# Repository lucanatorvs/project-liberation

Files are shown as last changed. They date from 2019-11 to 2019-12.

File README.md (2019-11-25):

# Project Liberation
Project Liberation is een weerstation welke doormiddel van een ESP-32 over WiFi
de meet-data naar het Britse meteorologisch instituut
([MetOffice](https://www.metoffice.gov.uk/)) communiceert zodat deze beschikbaar
worden in de [WOW-NL](https://wow.knmi.nl/) database van de KNMI.

## assembling
for assembling instructions pleas see the pdf at ./instructions/instructions.pdf

## flashing the esp
Use a 'USB to serial' programer and conect the pins: 3v3, GND, RXD, TXD, DTR and RTS. 
Remember that the RX on the programer sould go to the TX on the esp and so the pcb, and visversa.
In arduino, open the scetch and select the port of youre programer.
Install the esp32 boardmaniger by adding the url `https://dl.espressif.com/dl/package_esp32_index.json` to the "additional board maniger URLs" section in youre arduino settings.
A list of the drivers is given and if all the drivers are installed, you sould be able to flach the esp.

## Keeping our logs clean
Please read this and keep it in mind when writing commit messages:
[How to Write a Git Commit Message](https://chris.beams.io/posts/git-commit/)

Also, please put this in your `~/.gitconfig` (if you care why read 
[this](https://kalamuna.atlassian.net/wiki/display/KALA/Git+Workflow)):
```
[branch]
  autosetuprebase = always
[core]
  mergeoptions = --no-commit --no-ff
```

## Contibuting
Pull requests are welcome. For major changes, please open an issue first to discuss what you would like to change.

## Licence
[MIT](./LICENSE)

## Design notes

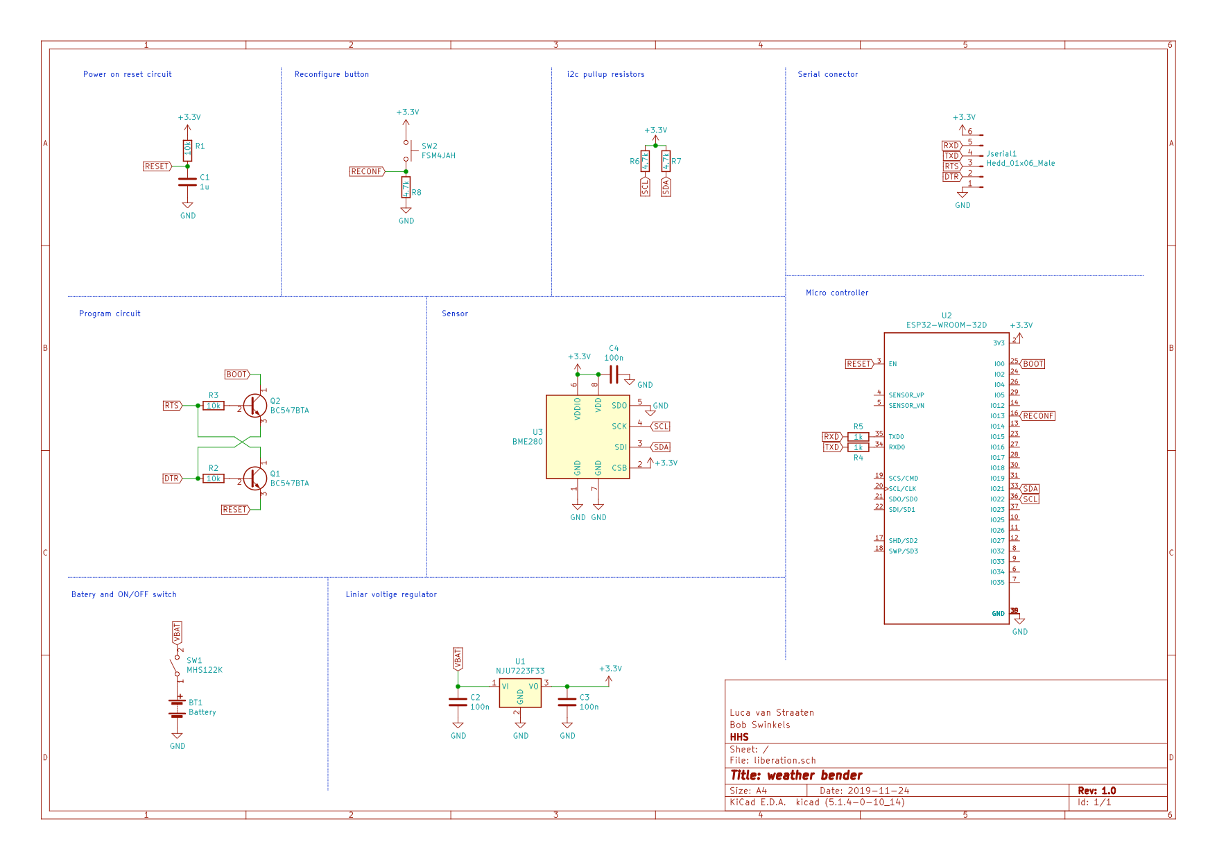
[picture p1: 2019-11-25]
instructions/schematic.png

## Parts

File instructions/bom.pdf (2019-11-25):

### bill of material

Id | Designator | Package | Quantity | Designation
1 | R3,R1,R2 | Weerstand | 3 | 10k
2 | C1 | Condensator | 1 | 1u
3 | C2,C3,C4 | Condensator | 3 | 100n
4 | Jserial1 | PinHeader_1x06_P2.54mm_Vertical | 1 | Hedd_01x06_Male
5 | Q2,Q1 | Transistor_npn | 2 | BC547BTA
6 | R5,R4 | Weerstand | 2 | 1k
7 | R6,R7,R8 | Weerstand | 3 | 4.7k
8 | SW1 | Schakelaar | 1 | MHS122K
9 | SW2 | Knop | 1 | FSM4JAH
10 | BT1 | Batterij houder | 1 | Battery
11 | U1 | Voltage regulator | 1 | NJU7223F33

1

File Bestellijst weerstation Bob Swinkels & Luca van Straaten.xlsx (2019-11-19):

# | Bedrijfsnaam | Naam van het product | Directe link naar product | Bestelnr. / Order code | Aantal | Prijs/st ; incl BTW | Totaal | Opmerking door/voor besteller
1 | Mouser | ESP32-WROOM-32D | https://nl.mouser.com/ProductDetail/Espressif-Systems/ESP32-WROOM-32D | 356-ESP32WROOM-32D | 27 | €4.14 | €111.73 | MCU
2 | Mouser | BME280 | https://nl.mouser.com/ProductDetail/Bosch-Sensortec/BME280 | 262-BME280 | 27 | €4.07 | €109.77 | Sensor
3 | Mouser | MHS122K | https://nl.mouser.com/ProductDetail/Apem/MHS122K?qs=sGAEpiMZZMtHXLepoqNyVZHUmh3BZZ%2FL5BB0Uv5Iez0%3D | 642-MHS122K | 27 | €1.51 | €40.84 | Power switch
4 | Mouser | FSM4JAH | https://nl.mouser.com/ProductDetail/TE-Connectivity-Alcoswitch/FSM4JAH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 | 506-FSM4JAH | 27 | €0.11 | €2.87 | Push button
5 | Mouser | Keystone 2477 | https://nl.mouser.com/ProductDetail/Keystone-Electronics/2477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 | 534-2477 | 27 | €1.63 | €44.10 | Battery holder
6 | Mouser | NJU7223F33 | https://nl.mouser.com/ProductDetail/NJR/NJU7223F33 | 513-NJU7223F33 | 27 | €1.12 | €30.19 | 3.3V Regulator
7 | Mouser | BC547BTA | https://nl.mouser.com/ProductDetail/ON-Semiconductor-Fairchild/BC547BTA | 512-BC547BTA | 100 | €0.06 | €6.41 | NPN-Transistor
8 | Mouser | MFR3-10KFC | https://nl.mouser.com/ProductDetail/Welwyn-Components-TT-Electronics/MFR3-10KFC | 756-MFR3-10KFC | 100 | €0.04 | €3.51 | 10k Resistor
9 | Mouser | MFR3-4K7FC | https://nl.mouser.com/ProductDetail/Welwyn-Components-TT-Electronics/MFR3-4K7FC | 756-MFR3-4K7FC | 100 | €0.04 | €3.51 | 4k7 Resistor
10 | Mouser | MFR3-1K0FC | https://nl.mouser.com/ProductDetail/Welwyn-Components-TT-Electronics/MFR3-1K0FC | 756-MFR3-1K0FC | 100 | €0.04 | €3.51 | 1k0 Resistor
11 | Mouser | K104K15X7RF53H5 | https://nl.mouser.com/ProductDetail/Vishay-BC-Components/K104K15X7RF53H5 | 594-K104K15X7RF53H5 | 125 | €0.05 | €6.05 | 100n Capacitor
12 | Mouser | 860020672005 | https://nl.mouser.com/ProductDetail/Wurth-Elektronik/860020672005 | 710-860020672005 | 40 | €0.09 | €3.63 | 1u Capacitor
13 | Mouser | LR6XWA/B2 | https://nl.mouser.com/ProductDetail/Panasonic-Battery/LR6XWA-B2 | 658-LR6XWA/2SB | 100 | €0.40 | €39.93 | Battery
 |  |  |  |  |  | Totaal: | €406.06 | inclusief BTW
 |  |  |  |  |  | Totaal: | €16.24 | Per unit (+ ca. €2,- voor de PCB)

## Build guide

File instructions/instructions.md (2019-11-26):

---
author:
- Bob Swinkels
- Luca van Straaten 
header-includes:
	- \usepackage{pdfpages}
...

# WOW Monitor
### A project by Bob Swinkels and Luca van Straaten
 
--- 

## start:
do you have all the components?

check your components against the bill of materials. 

|Id |Designator|Package |Quantity|Designation |
|---|---|---|---|---|
|1  |R3,R1,R2  |Weerstand |3 |10k |
|2  |C1 |Condensator |1 |1u |
|3  |C2,C3,C4  |Condensator |3 |100n |
|4  |Jserial1  |PinHeader_1x06_P2.54mm_Vertical|1 |Hedd_01x06_Male|
|5  |Q2,Q1 |Transistor_npn |2 |BC547BTA |
|6  |R5,R4 |Weerstand |2 |1k |
|7  |R6,R7,R8  |Weerstand |3 |4.7k |
|8  |SW1 |Schakelaar |1 |MHS122K |
|9  |SW2 |Knop |1 |FSM4JAH |

## soldering!

Now it is time to start SOLDERING!!!
Start withe the small components and finish with the battery holder, remember to put some double sided tape on the battery holder befor you solder it for strength.

So start with the resistors (the small cilinders with 2 wires), the value is written on the piece of paper. you can also decode the colorcode, look at the decoder that is attached or just google "resistor color code".

Now continu with the progressively larger components. after you are done sodering, "flash" your bord with the Arduino IDE. Bob or luca can help you with that, but you can do it yourself! (witch is arguably more fun) Just follow the instructions on the GitHub projectpage. https://github.com/lucanatorvs/project-liberation

\pagebreak

## setting up your wether station to connect with the WOW server:
when you get home, start by setting up your account with the metoffice. go to http://wow.metoffice.gov.uk/sites and klick "Sign Up", "new account", fill in your info and register!
now check your email for login instructions. click the link in your mail and log back in. now go to "http://wow.metoffice.gov.uk" and click on "enter a site".

now fill in the location, and the site name, the time zone, and as the "Authentication Key" think of an 6 digit number. NOT "123456". and remember this!!!
At "Above Ground Measurements" for "Air Temperature" select "Hecto Pascal". 
At "Pressure" for "Pressure At Station" select "Hecto Pascal"
At "Other Observations" for "Relative Humidity" select "Captured"
leave the rest alone.
now fill in other relative information is aplicable.
after you filed in all your info click accept.

Now if you get the "Site Created!" message, your almost done! click "view sites" and in the colom "Search for Users Sites:" check out your new site. under the map is a code like "8b9cd787-930f-ea11-b265-0003ff5990ac", this is your site id, remember to copy it without the brackets but with the " - ".
now turn on your WOW monitor sensor bord, and hold the button. hold it until a new wifi network is avalible, "WOW-MONITOR-****" klick it and you should be redirected to a website in wich you have to fill in the "site id" and the 6 digit number. then connect to your wifi network.

http://wow.metoffice.gov.uk/sites

https://github.com/lucanatorvs/project-liberation

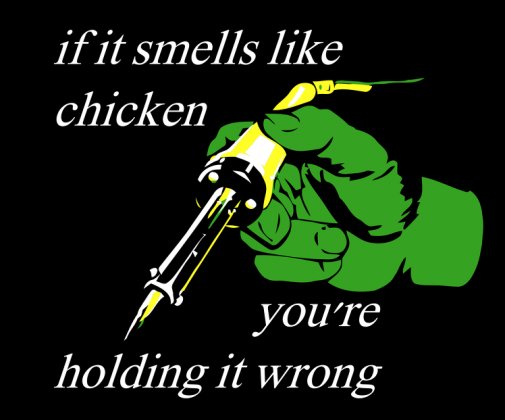
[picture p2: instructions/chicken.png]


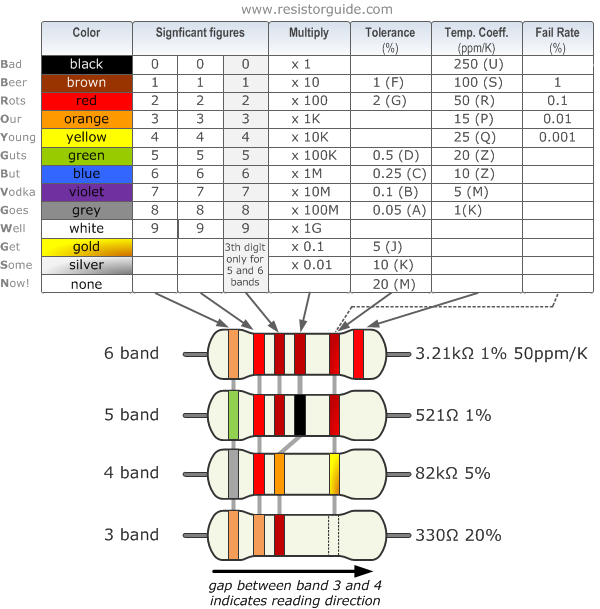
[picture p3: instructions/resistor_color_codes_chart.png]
van: https://www.resistorguide.com/standards-and-codes/resistor-color-code/resistor_color_codes_chart/


\includepdf[page={1}]{schematic.pdf}

\includepdf[page={1}]{pcb.pdf}

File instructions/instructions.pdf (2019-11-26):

## WOW Monitor

A project by Bob Swinkels and Luca van Straaten

start:

do you have all the components?

check your components against the bill of materials.

Id | Designator | Package | Quantity | Designation
1 | R3,R1,R2 | Weerstand | 3 | 10k
2 | C1 | Condensator | 1 | 1u
3 | C2,C3,C4 | Condensator | 3 | 100n
4 | Jserial1 | PinHeader_1x06_P2.54mm_Vertical | 1 | Hedd_01x06_Male
5 | Q2,Q1 | Transistor_npn | 2 | BC547BTA
6 | R5,R4 | Weerstand | 2 | 1k
7 | R6,R7,R8 | Weerstand | 3 | 4.7k
8 | SW1 | Schakelaar | 1 | MHS122K
9 | SW2 | Knop | 1 | FSM4JAH

soldering!

Now it is time to start SOLDERING!!! Start withe the small components and finish with the battery holder, remember to put some double sided tape on the battery holder befor you solder it for strength.

So start with the resistors (the small cilinders with 2 wires), the value is written on the piece of paper. you can also decode the colorcode, look at the decoder that is attached or just google “resistor color code”.

Now continu with the progressively larger components. after you are done sodering, “flash” your bord with the Arduino IDE. Bob or luca can help you with that, but you can do it yourself! (witch is arguably more fun) Just follow the instructions on the GitHub projectpage. https://github.com/lucanatorvs/project-liberation

1

setting up your wether station to connect with the WOW server:

when you get home, start by setting up your account with the metoffice. go to http://wow.metoffice.gov.uk/sites and klick “Sign Up”, “new account”, fill in your info and register! now check your email for login instructions. click the link in your mail and log back in. now go to “http://wow.metoffice.gov.uk” and click on “enter a site”.

now fill in the location, and the site name, the time zone, and as the “Authentication Key” think of an 6 digit number. NOT “123456”. and remember this!!! At “Above Ground Measurements” for “Air Temperature” select “Hecto Pascal”. At “Pressure” for “Pressure At Station” select “Hecto Pascal” At “Other Observations” for “Relative Humidity” select “Captured” leave the rest alone. now fill in other relative information is aplicable. after you filed in all your info click accept.

Now if you get the “Site Created!” message, your almost done! click “view sites” and in the colom “Search for Users Sites:” check out your new site. under the map is a code like “8b9cd787-930f-ea11-b265-0003ff5990ac”, this is your site id, remember to copy it without the brackets but with the " - “. now turn on your WOW monitor sensor bord, and hold the button. hold it until a new wifi network is avalible,”WOW-MONITOR-****" klick it and you should be redirected to a website in wich you have to fill in the “site id” and the 6 digit number. then connect to your wifi network.

Figure 1: http://wow.metoffice.gov.uk/sites

2

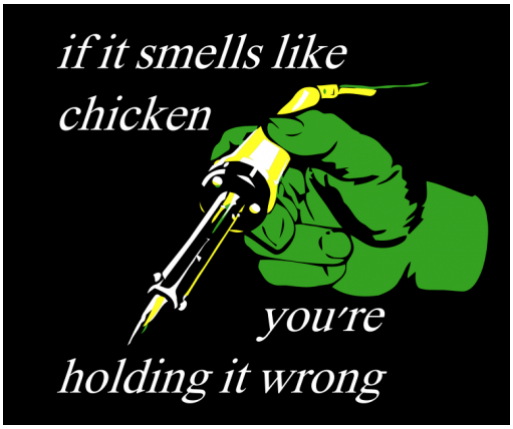
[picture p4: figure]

3

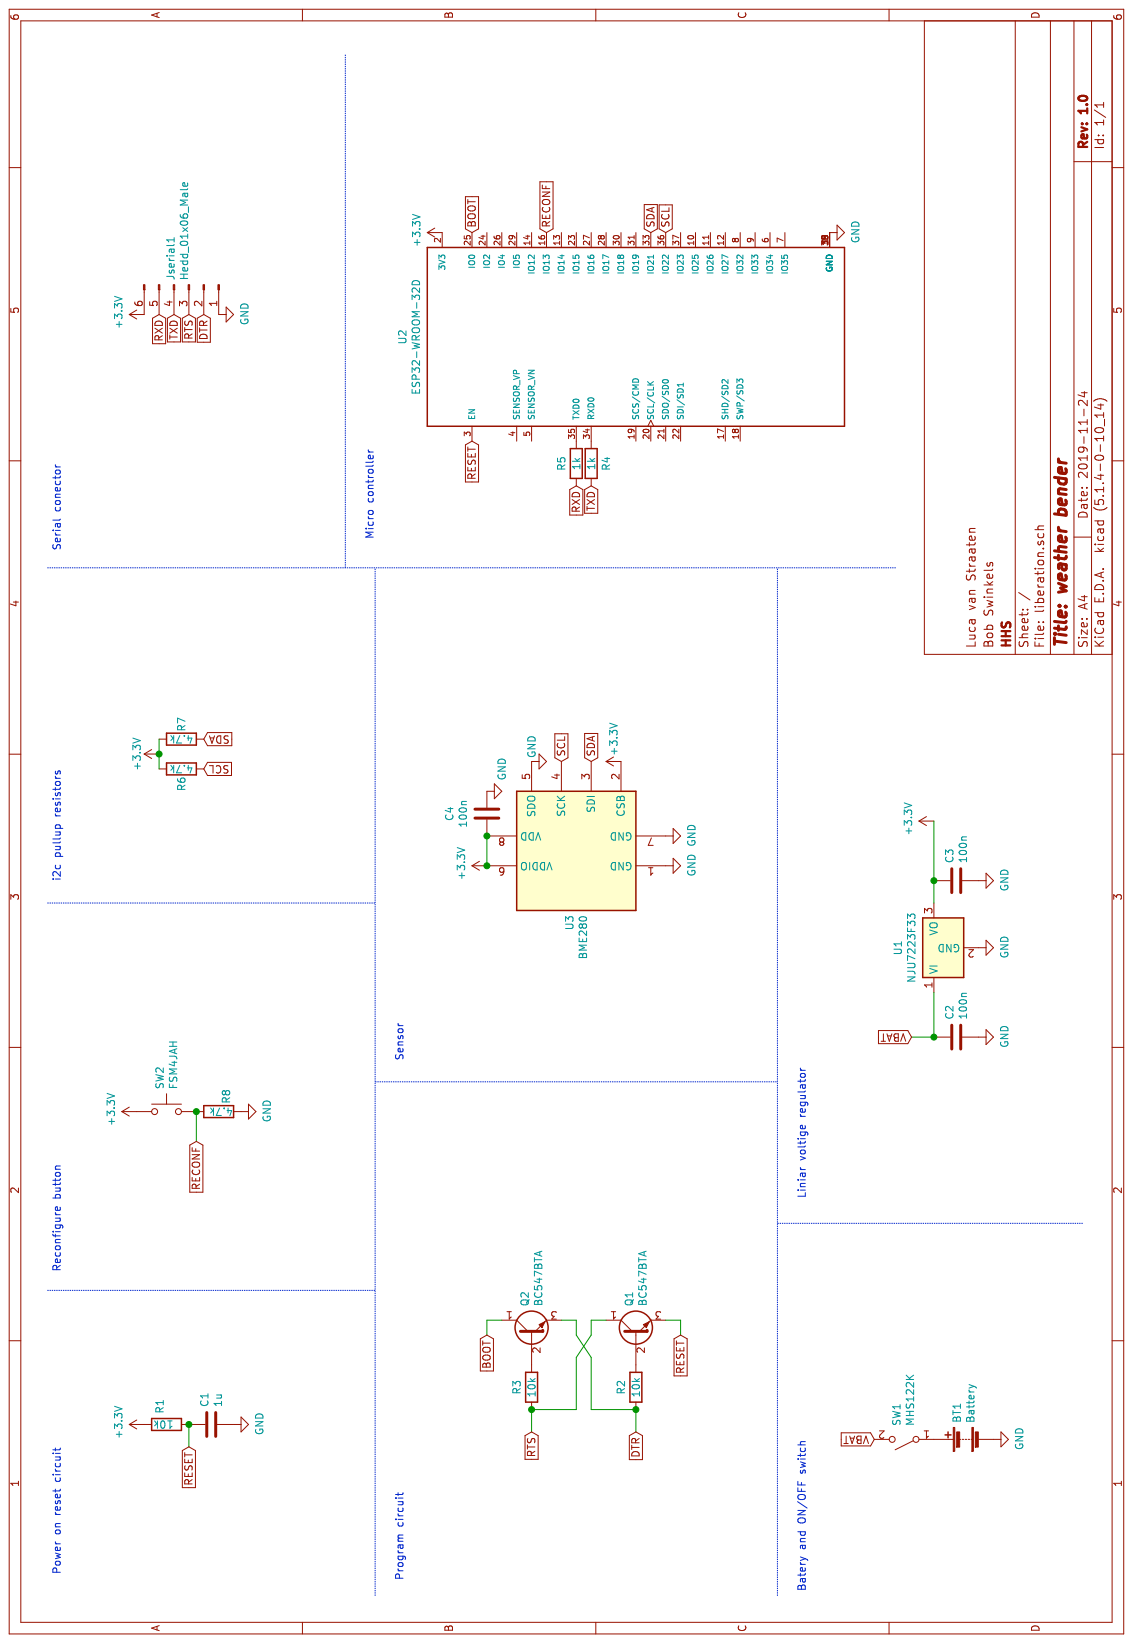
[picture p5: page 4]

Figure 2: https://github.com/lucanatorvs/project-liberation


Figure 3: van: https://www.resistorguide.com/standards-and-codes/resistorcolor-code/resistor_color_codes_chart/

5

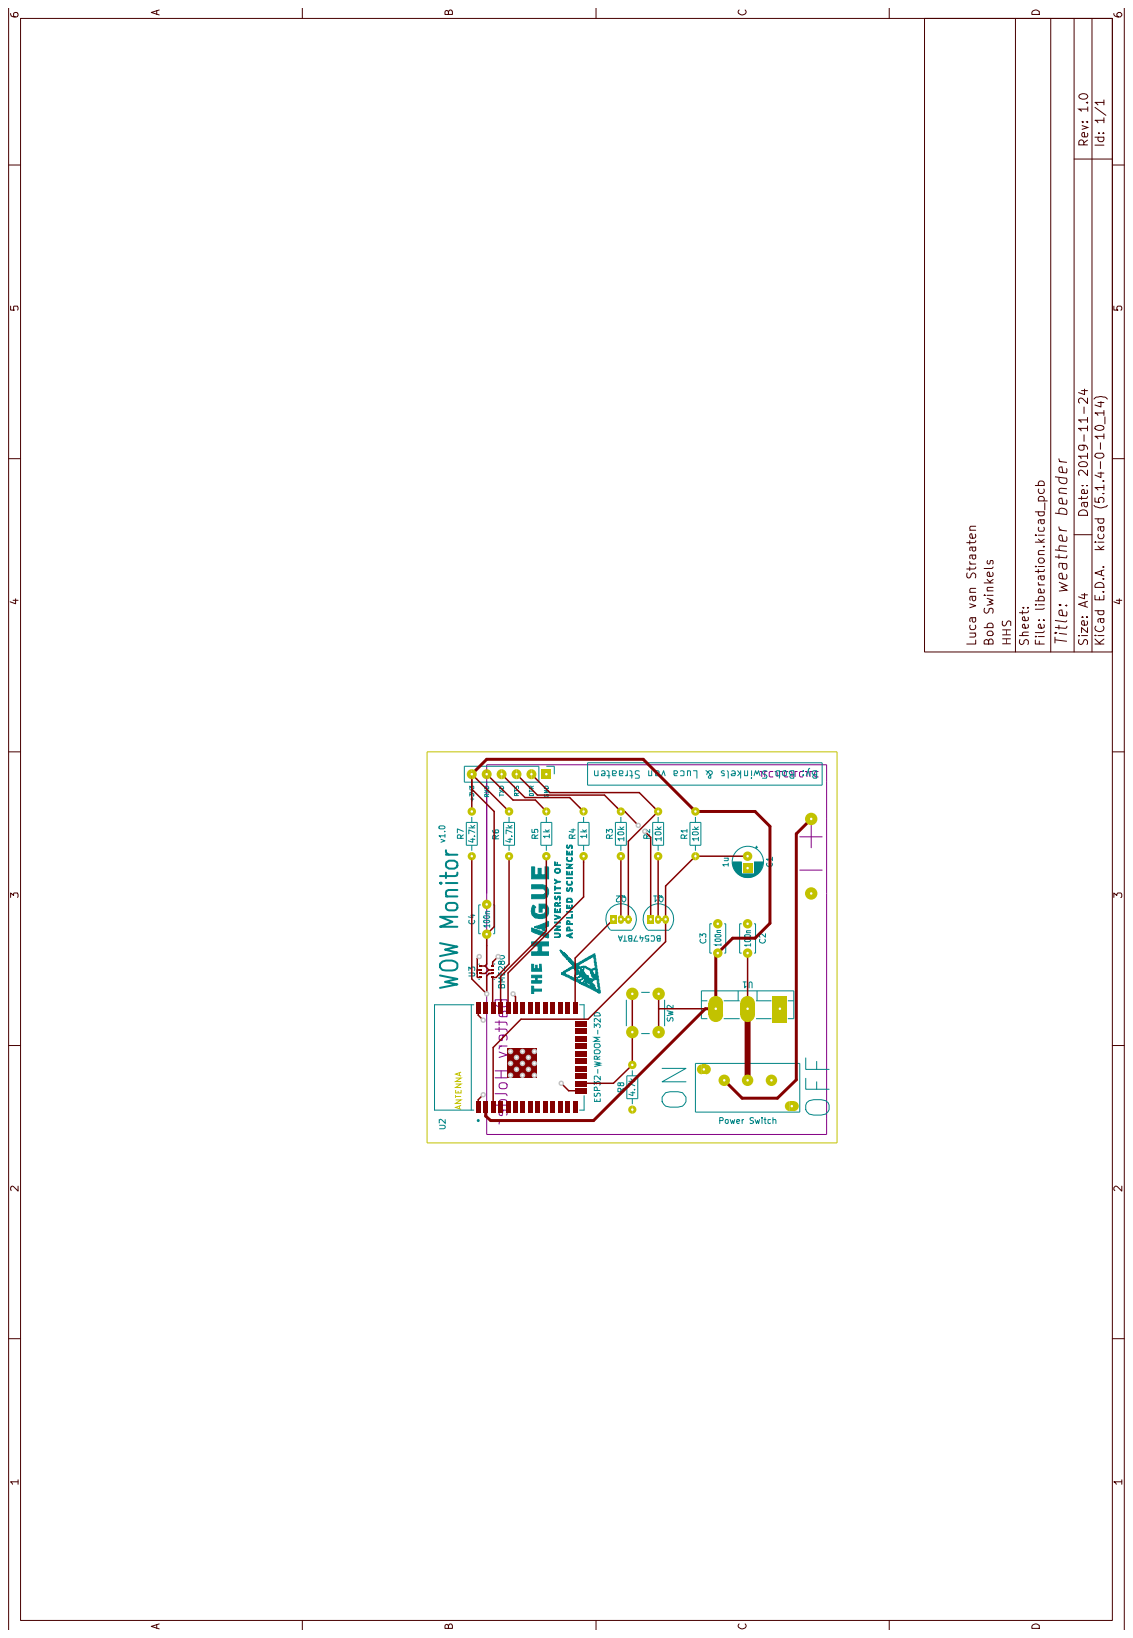
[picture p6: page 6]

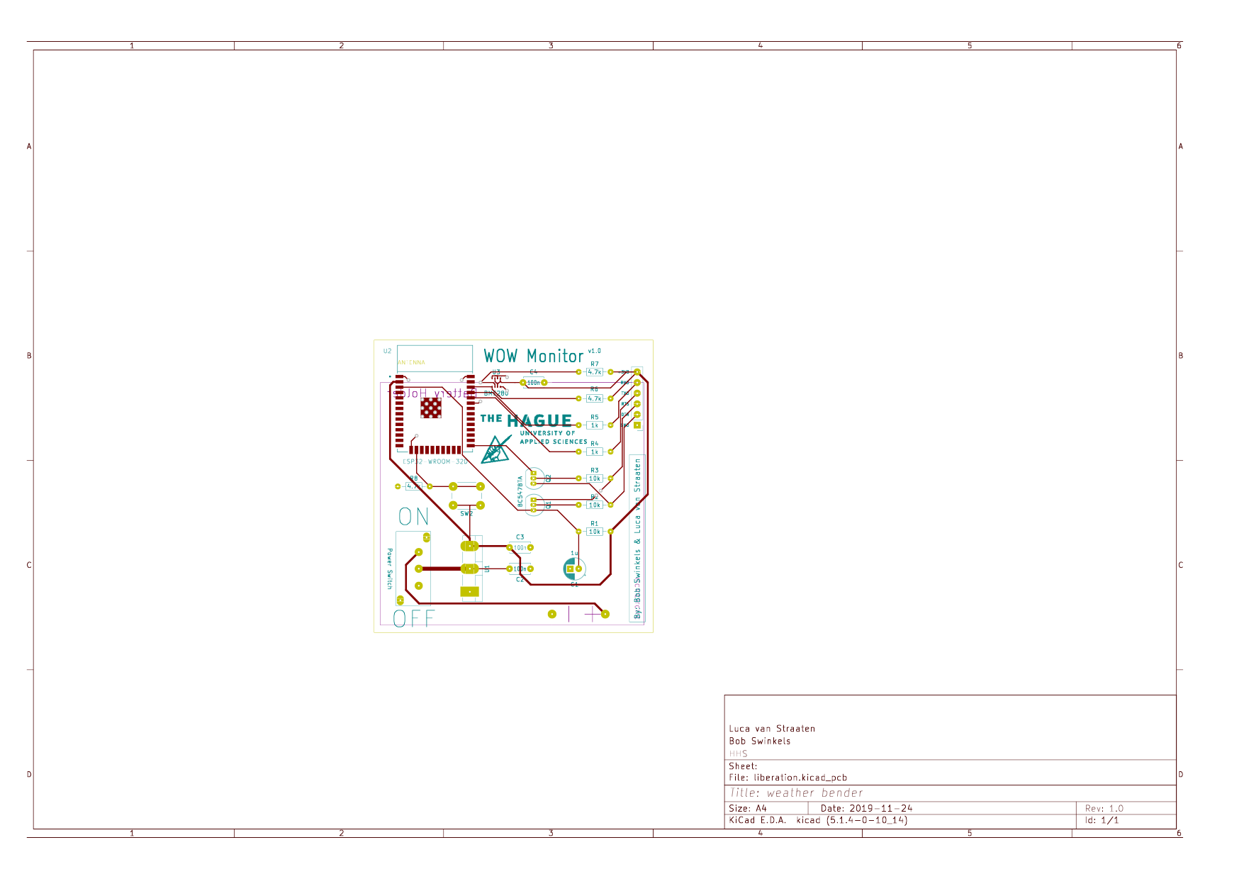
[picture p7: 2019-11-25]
instructions/pcb.png

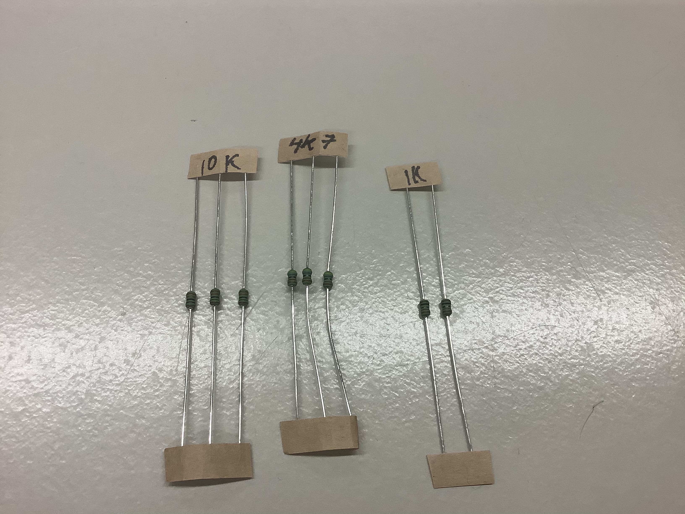
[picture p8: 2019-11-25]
instructions/IMG_0134.jpeg

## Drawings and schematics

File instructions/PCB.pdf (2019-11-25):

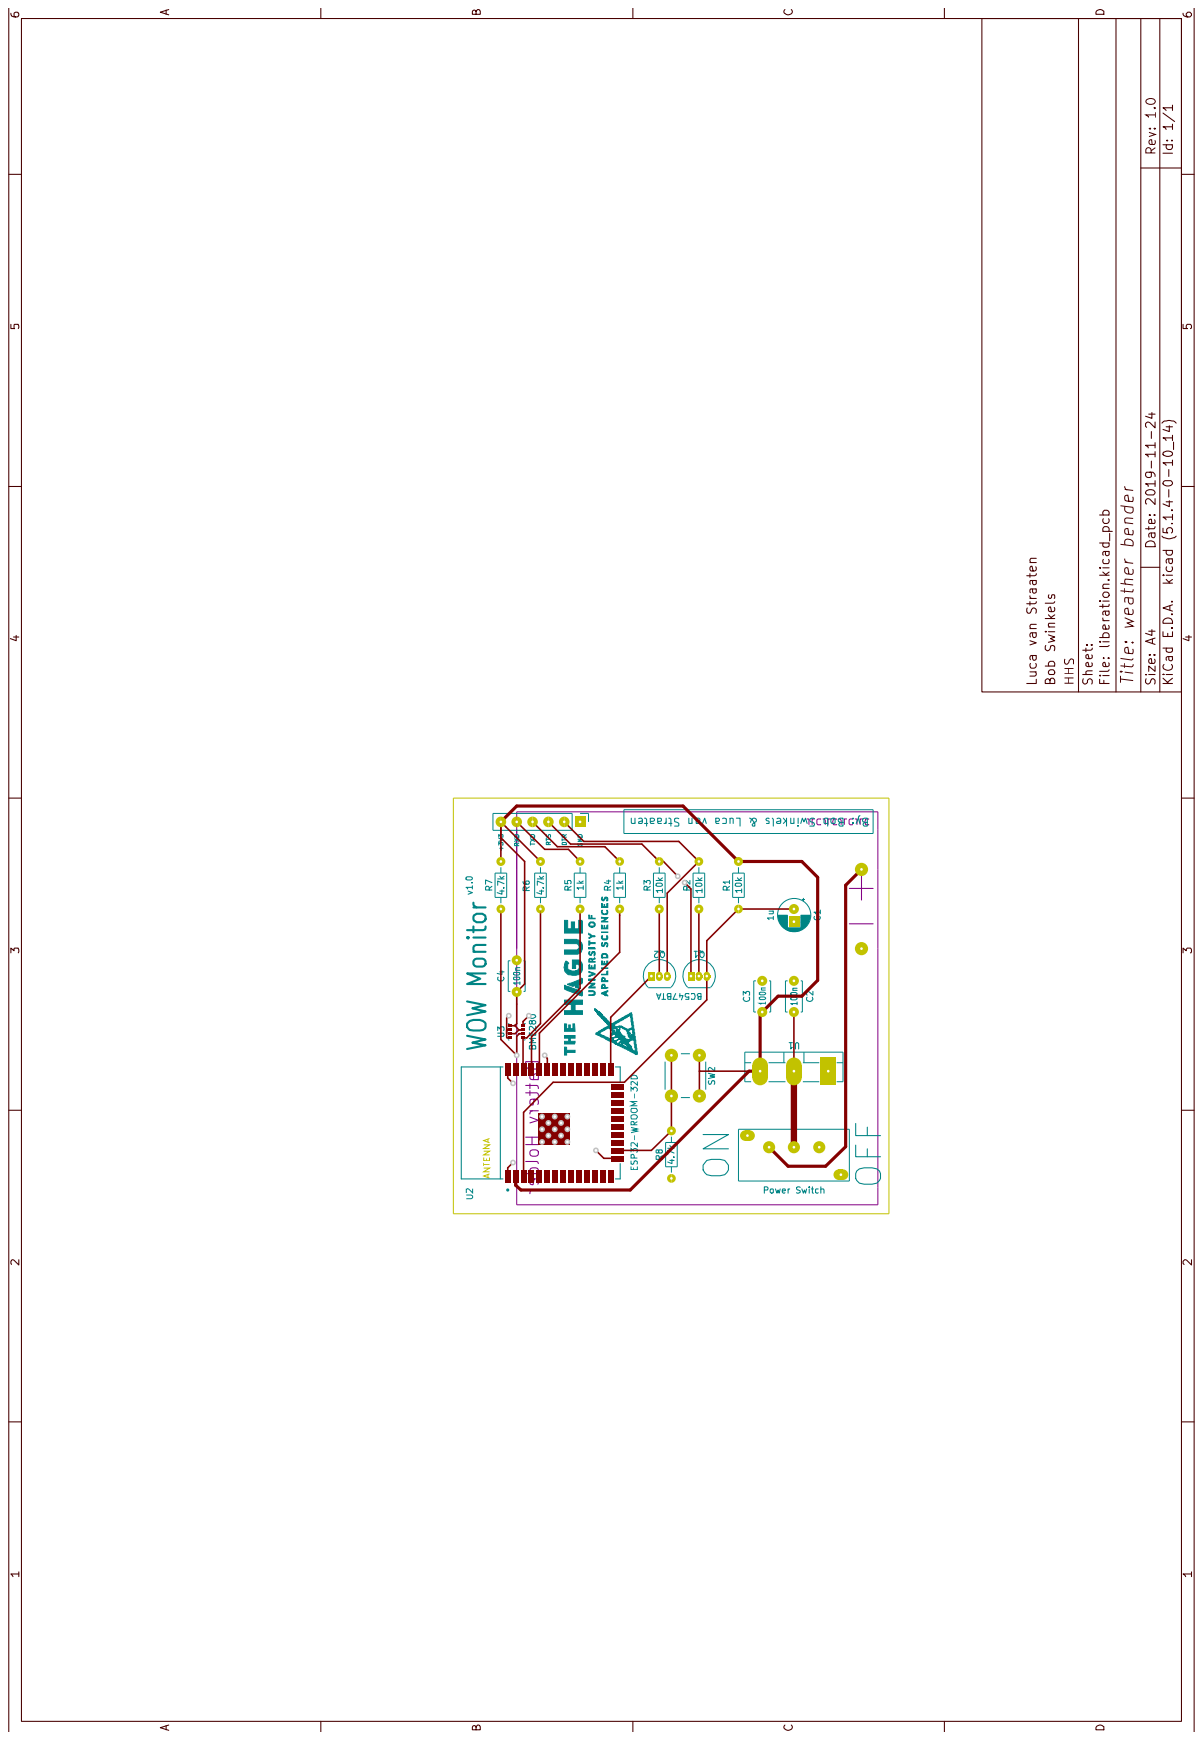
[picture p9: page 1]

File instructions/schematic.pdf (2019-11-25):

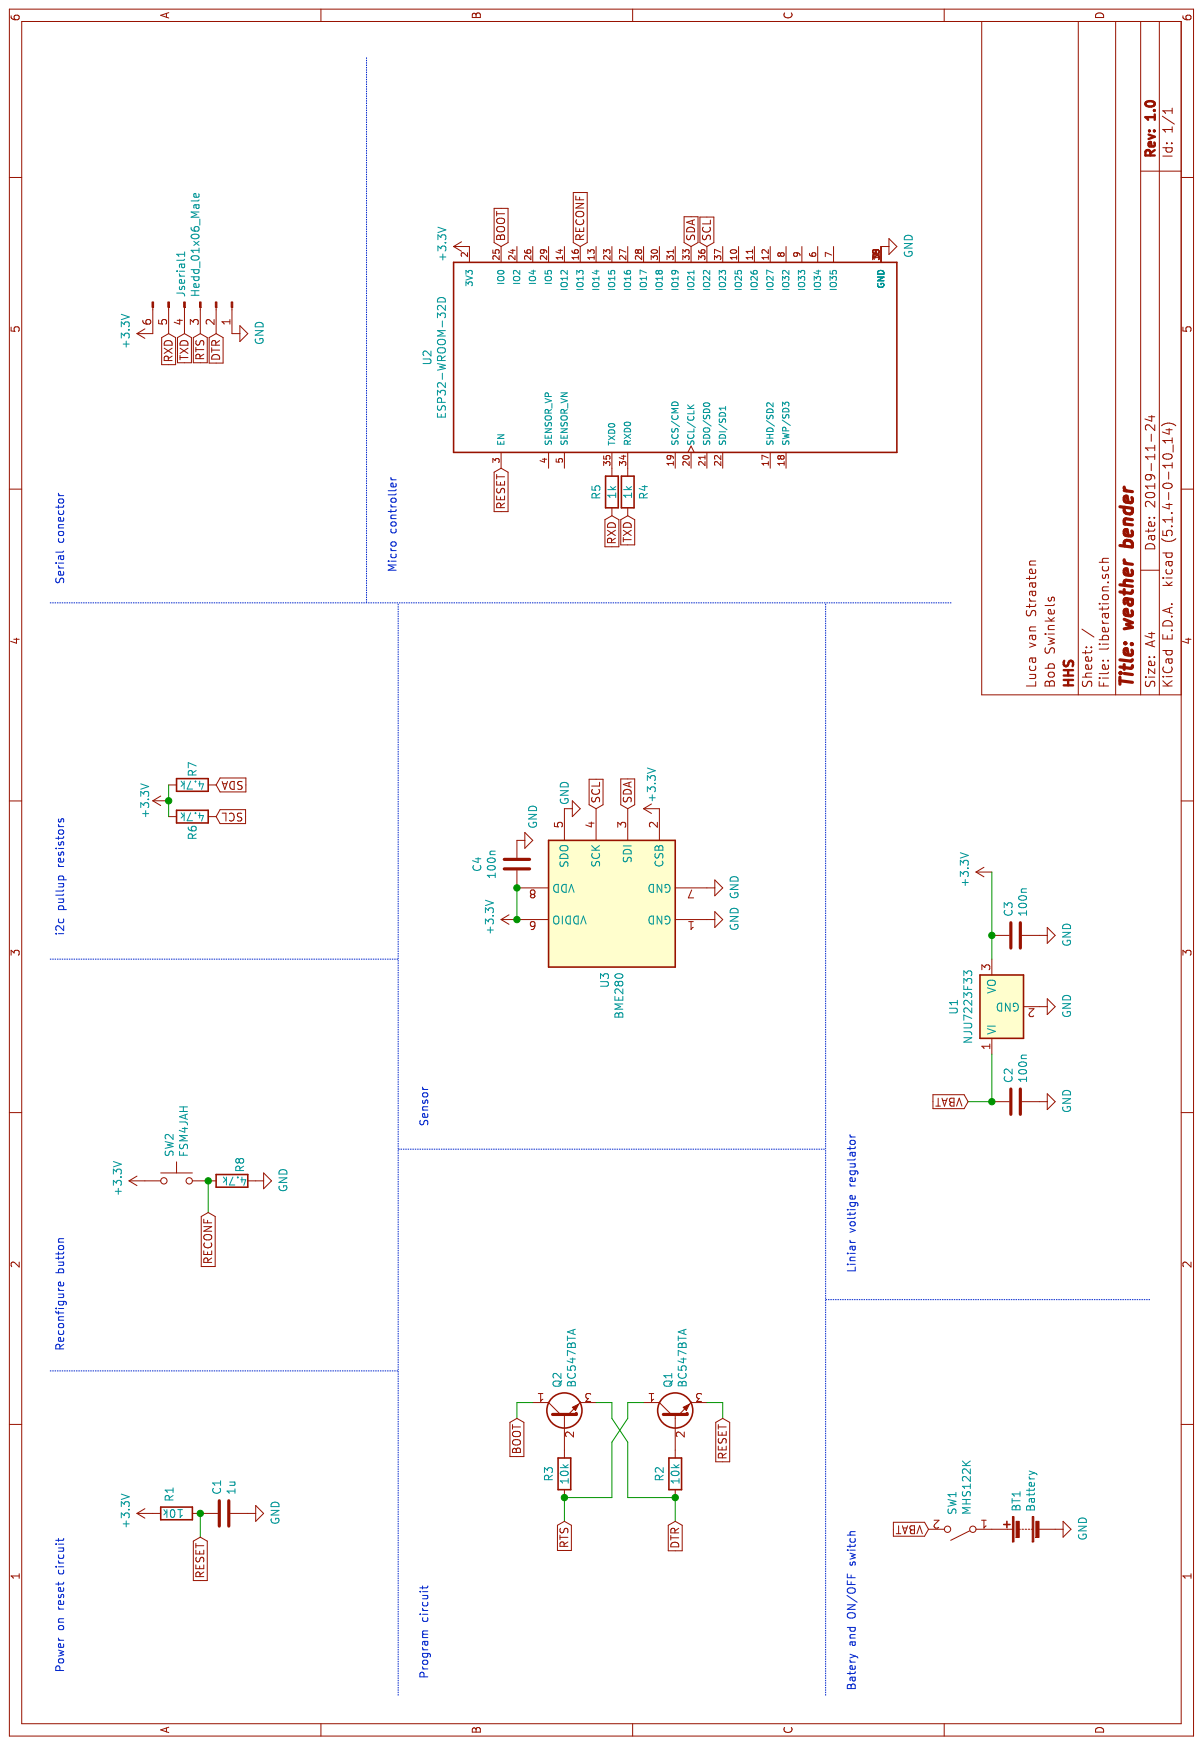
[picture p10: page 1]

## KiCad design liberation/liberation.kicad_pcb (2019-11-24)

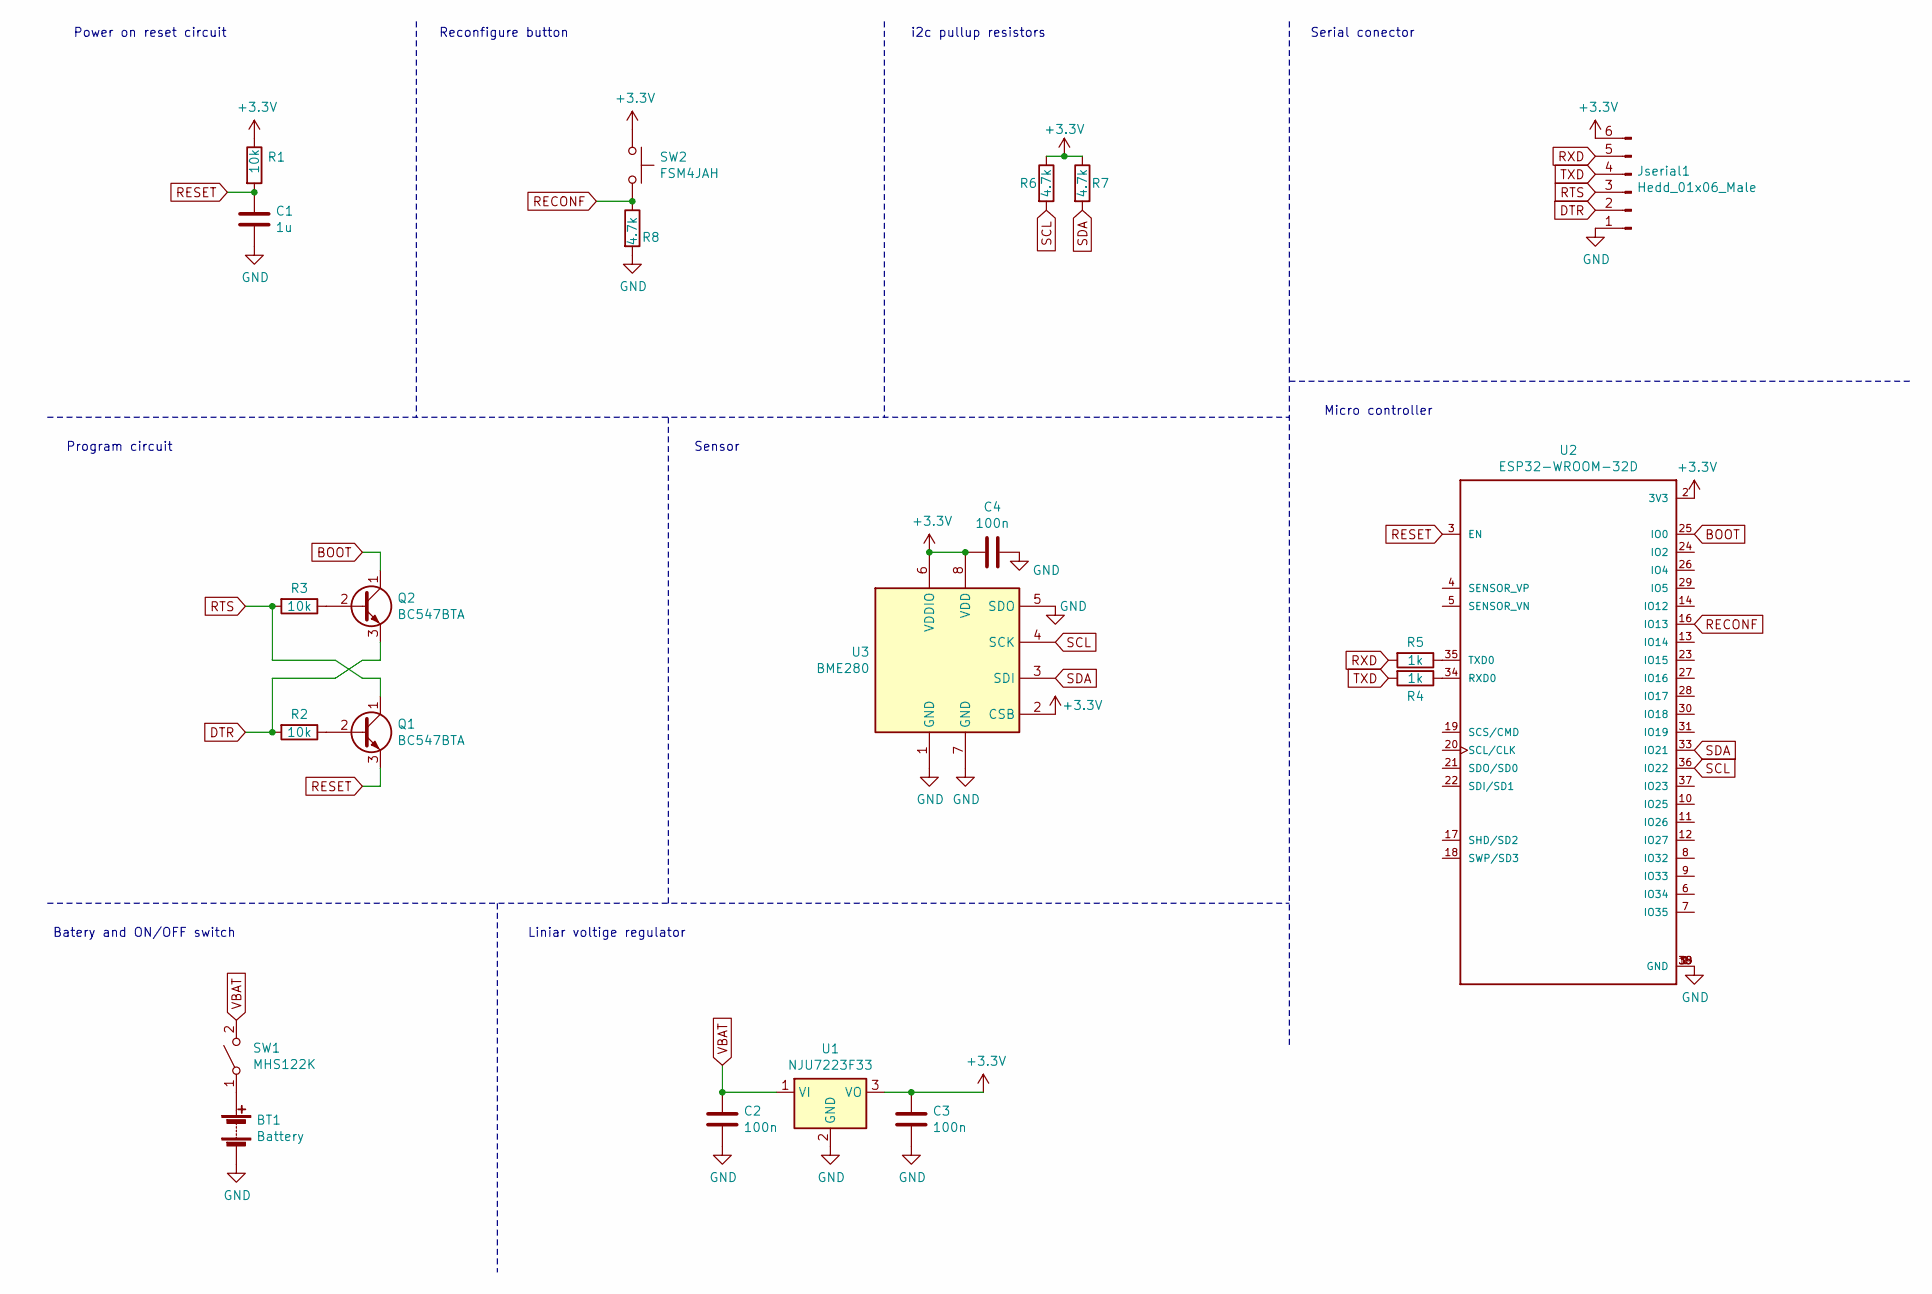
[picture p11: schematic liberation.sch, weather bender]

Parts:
BT1: Battery; keystone_2477
C1: 1u; CP_Radial_D5.0mm_P2.00mm
C2, C3, C4: 100n; C_Disc_D4.7mm_W2.5mm_P5.00mm
Jserial1: Hedd_01x06_Male; PinHeader_1x06_P2.54mm_Vertical
Q1, Q2: BC547BTA; TO-92_Inline
R1, R2, R3: 10k; R_Axial_DIN0204_L3.6mm_D1.6mm_P7.62mm_Horizontal
R4, R5: 1k; R_Axial_DIN0204_L3.6mm_D1.6mm_P7.62mm_Horizontal
R6, R7, R8: 4.7k; R_Axial_DIN0204_L3.6mm_D1.6mm_P7.62mm_Horizontal
SW1: MHS122K; MHS122
SW2: FSM4JAH; SW_PUSH_6mm_H5mm
U1: NJU7223F33
U2: ESP32-WROOM-32D; MODULE_ESP32-WROOM-32D
U3: BME280; Bosch_LGA-8_2.5x2.5mm_P0.65mm_ClockwisePinNumbering

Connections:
+3V3: C3.1, C4.2, Jserial1.6, R1.1, R6.1, R7.1, SW2.1, U1.3 (VO), U2.2 (3V3), U3.2 (CSB), U3.6 (VDDIO), U3.8 (VDD)
BOOT: Q2.1 (C), U2.25 (IO0)
DTR: Jserial1.2, Q2.3 (E), R2.2
GND: BT1.2 (-), C1.2, C2.2, C3.2, C4.1, Jserial1.1, R8.2, U1.2 (GND), U2.1 (GND), U2.15 (GND), U2.38 (GND), U2.39 (GND), U3.1 (GND), U3.5 (SDO), U3.7 (GND)
unnamed: BT1.1 (+), SW1.1 (A)
unnamed: Q1.2 (B), R2.1
unnamed: Q2.2 (B), R3.1
unnamed: R4.1, U2.34 (RXD0)
unnamed: R5.1, U2.35 (TXD0)
RECONF: R8.1, SW2.2, U2.16 (IO13)
RESET: C1.1, Q1.3 (E), R1.2, U2.3 (EN)
RTS: Jserial1.3, Q1.1 (C), R3.2
RXD: Jserial1.5, R5.2
SCL: R6.2, U2.36 (IO22), U3.4 (SCK)
SDA: R7.2, U2.33 (IO21), U3.3 (SDI)
TXD: Jserial1.4, R4.2
VBAT: C2.1, SW1.2 (B), U1.1 (VI)

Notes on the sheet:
Micro controller
Serial conector
i2c pullup resistors
Power on reset circuit
Reconfigure button
Batery and ON/OFF switch
Program circuit
Sensor
Liniar voltige regulator

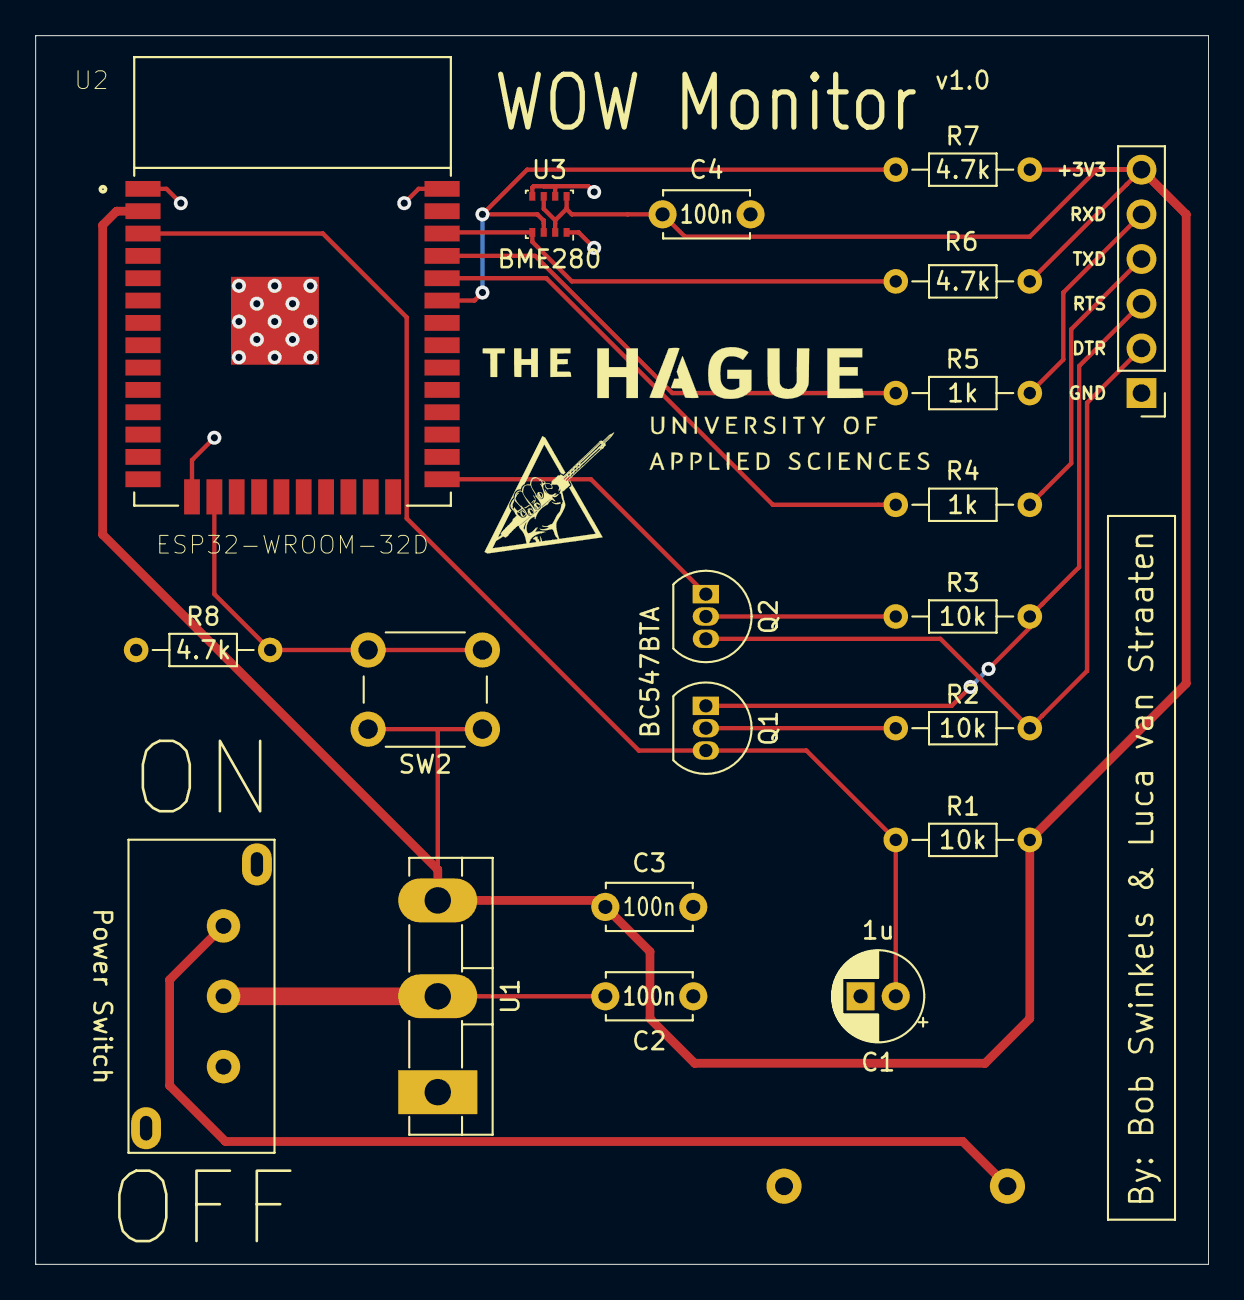
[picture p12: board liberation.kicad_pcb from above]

Board: 2 copper layers, 66.7 x 69.8 mm, 21 parts (1 on the bottom side), 17 nets.

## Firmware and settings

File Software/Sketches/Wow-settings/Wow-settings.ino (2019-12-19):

/*
  Elements.ino, Example for the AutoConnect library.
  Copyright (c) 2019, Hieromon Ikasamo
  https://github.com/Hieromon/AutoConnect
  This software is released under the MIT License.
  https://opensource.org/licenses/MIT

  This example demonstrates the typical behavior of AutoConnectElement.
  It also represents a basic structural frame for saving and reusing
  values entered in a custom web page into flash.
*/

#include "src/AutoConnect/AutoConnect.h"
#include <WiFi.h>
#include <WebServer.h>
#include <SPIFFS.h>
using WebServerClass = WebServer;
#include <FS.h>
#include "time.h" // For NTP
#include <HTTPClient.h>

#include <Wire.h>
#include <Adafruit_Sensor.h>
#include <Adafruit_BME280.h>

#define PARAM_FILE "/wow_settings.json"

#define uS_TO_S_FACTOR    1000000ULL   // Conversion factor for micro seconds to seconds
#define TIME_TO_SLEEP     1800         // Time ESP32 will go to sleep (in seconds) 30 min * 60 sec = 1800 sec
#define TIME_BEFORE_RETRY 10           // Time ESP32 will wait before WiFi  connectoin retry

RTC_DATA_ATTR int firstBoot = 1;

static const char PAGE_WOW[] PROGMEM = R"(
{
  "uri": "/wow-settings",
  "title": "WOW Settings",
  "menu": true,
  "element": [
    {
      "name": "text",
      "type": "ACText",
      "value": "<b>Stap 1:</b> Instellingen van MetOffice om de data te kunnen uploaden via de WOW-API",
      "style": "font-family:Arial;font-size:18px;font-weight:400;color:#191970"
    },
    {
      "name": "site_id",
      "type": "ACInput",
      "label": "Site ID",
      "placeholder": "XXXXXXXX-XXXX-XXXX-XXXX-XXXXXXXXXXXX",
      "pattern": "^[a-z0-9]{8}-[a-z0-9]{4}-[a-z0-9]{4}-[a-z0-9]{4}-[a-z0-9]{12}$"
    },
    {
      "name": "site_key",
      "type": "ACInput",
      "label": "6-Digit PIN",
      "placeholder": "6 digit site key",
      "pattern": "^[0-9]{6}$"
    },
    {
      "name": "save",
      "type": "ACSubmit",
      "value": "Volgende",
      "uri": "/save"
    }
  ]
}
)";

static const char PAGE_SAVE[] PROGMEM = R"(
{
  "uri": "/save",
  "title": "WOW Settings",
  "menu": false,
  "element": [
    {
      "name": "caption",
      "type": "ACText",
      "value": "<b>Stap 2:</b> Nu dient u te verbinden met een WiFi netwerk. Zodra dit is gebeurd wordt de verbinding (en deze website) automatisch gesloten.",
      "style": "font-family:Arial;font-size:18px;font-weight:400;color:#191970"
    },
    {
      "name": "ok",
      "type": "ACSubmit",
      "value": "Volgende",
      "uri": "/_ac/open"
    }
  ]
}
)";

unsigned long time_now = 0;

// NTP Server
const char* ntpServer = "nl.pool.ntp.org";
const long  gmtOffset_sec = 3600;
const int   daylightOffset_sec = 3600;

WebServerClass  server;
AutoConnect portal(server);
AutoConnectConfig config;
AutoConnectAux  wowAux;
AutoConnectAux  saveAux;

String site_id;
String site_key;

float temperature;
float pressure;
float humidity;

struct tm timeinfo;
char timeStringBuff[50]; //50 chars should be enough

Adafruit_BME280 bme; // I2C

void open_portal() {
  // Load a custom web page described in JSON as PAGE_ELEMENT and
  // register a handler. This handler will be invoked from
  // AutoConnectSubmit named the Load defined on the same page.
  wowAux.load(FPSTR(PAGE_WOW));
  wowAux.on([] (AutoConnectAux& aux, PageArgument& arg) {
      SPIFFS.begin(true);
      File param = SPIFFS.open(PARAM_FILE, "r");
      if (param){
        aux.loadElement(param, { "text", "site_id", "site_key" } );
        param.close();
      }
      SPIFFS.end();
    return String();
  });

  saveAux.load(FPSTR(PAGE_SAVE));
  saveAux.on([] (AutoConnectAux& aux, PageArgument& arg) {
    SPIFFS.begin(true);
    File param = SPIFFS.open(PARAM_FILE, "w");
    
    if (param) {
      // Save as a loadable set for parameters.
      wowAux.saveElement(param, { "text", "site_id", "site_key" });
      param.close();
      // Read the saved elements again to display.
      param = SPIFFS.open(PARAM_FILE, "r");
      param.close();
    }
    
    SPIFFS.end();
    return String();
  });

  portal.join({ wowAux, saveAux });
  config.title = "WOW Monitor"; // Menu title
  config.apid = "WOW-MONITOR-" + String((uint32_t)(ESP.getEfuseMac() >> 32), HEX); // SSID
  Serial.println("apid set to: " + config.apid);
  config.immediateStart = true;
  config.portalTimeout = 60000; // Will time out in 1 minute
  config.psk  = ""; // Password
  portal.config(config);
  portal.begin();
  time_now = millis();
  while(millis() < time_now + 1000){
    //keep server alive approx. 1000 ms
    portal.handleClient();
  }
}

void takeMeasurement(){
  bme.takeForcedMeasurement();

  temperature = bme.readTemperature() * 1.8 + 32;
  Serial.print("Temperature = ");
  Serial.print(bme.readTemperature() * 1.8 + 32);
  Serial.println(" *F");

  pressure = bme.readPressure() / 3386.0F;
  Serial.print("Pressure = ");
  Serial.print(bme.readPressure() / 3386.0F);
  Serial.println(" inch of mercury");
  
  humidity = bme.readHumidity();
  Serial.print("Humidity = ");
  Serial.print(bme.readHumidity());
  Serial.println(" %");
  
  Serial.println();
}

void get_wow_settings(){
  SPIFFS.begin(true);
    File param = SPIFFS.open(PARAM_FILE, "r");
    if (param){
      DynamicJsonDocument doc(1024);
      deserializeJson(doc, param);
      site_id = doc[1]["value"].as<String>();
      Serial.println("Site ID = " + site_id);
      site_key = doc[2]["value"].as<String>();
      Serial.println("Site PIN = " + site_key);
      param.close();
    }
    SPIFFS.end();
}

void sendData() {
  Serial.println("Upload measurement");
  
   HTTPClient http;   

   //Specify destination for HTTP request
   http.begin("http://wow.metoffice.gov.uk/automaticreading?siteid=" + String(site_id) + "&siteAuthenticationKey=" + String(site_key) + "&dateutc=" + String(timeStringBuff) + "&baromin=" + pressure + "&humidity=" + String(humidity) + "&tempf=" + String(temperature) + "&softwaretype=wowmonitor1.0");
   Serial.println("http://wow.metoffice.gov.uk/automaticreading?siteid=" + String(site_id) + "&siteAuthenticationKey=" + String(site_key) + "&dateutc=" + String(timeStringBuff) + "&baromin=" + pressure + "&humidity=" + String(humidity) + "&tempf=" + String(temperature) + "&softwaretype=wowmonitor1.0");
 
   int httpResponseCode = http.GET();   //Send the actual GET request
 
   if(httpResponseCode>0){
 
    String response = http.getString(); //Get the response to the request
 
    Serial.println(httpResponseCode);   //Print return code
    Serial.println(response);           //Print request answer
 
   }else{
 
    Serial.print("Error on sending POST: ");
    Serial.println(httpResponseCode);
 
   }
 
   http.end();  //Free resources
}

void setup() {
  delay(1000);
  Serial.begin(115200);
  Serial.println();

  esp_sleep_enable_timer_wakeup(TIME_TO_SLEEP * uS_TO_S_FACTOR); // Wake up every X seconds
  Serial.println("Setup ESP32 to sleep for every " + String(TIME_TO_SLEEP) + " Seconds");

  esp_sleep_enable_ext0_wakeup(GPIO_NUM_13, 1); // Wake-up when button is pressed
  Serial.println("Setup ESP32 to wake on button press");

  if (! bme.begin(&Wire)) {
      Serial.println("Could not find a valid BME280 sensor, check wiring!");
  }

  bme.setSampling(Adafruit_BME280::MODE_FORCED,
                    Adafruit_BME280::SAMPLING_X1, // temperature
                    Adafruit_BME280::SAMPLING_X1, // pressure
                    Adafruit_BME280::SAMPLING_X1, // humidity
                    Adafruit_BME280::FILTER_OFF   );
                    
  if (firstBoot == 1){
    Serial.println("First boot, going back to sleep again");
    takeMeasurement();
    firstBoot = 0;
  } else {
    esp_sleep_wakeup_cause_t wakeup_reason;
    wakeup_reason = esp_sleep_get_wakeup_cause();
  
    if (wakeup_reason == ESP_SLEEP_WAKEUP_EXT0) {
      Serial.println("Wakeup caused by external signal using RTC_IO");
      open_portal();
      firstBoot = 1; // Reset firstBoot to start all over
      Serial.println("Set firstBoot to true");
    } else {
      Serial.println("Wakeup caused by timer");
  
      takeMeasurement();
      get_wow_settings();
  
      config.autoReconnect = true; // Automatically attempts to reconnect past access point
      config.autoRise = false;
      portal.config(config);
      Serial.println("Setup wifi connection");
  
      Serial.println("Try to connect to WiFi...");
      portal.begin();
  
      if (WiFi.status() == WL_CONNECTED) {
          Serial.println("WiFi connection success");
          configTime(0, 0, ntpServer); // Get time
          getLocalTime(&timeinfo);
          time_now = millis();
          while(millis() < time_now + 500){
            //keep wait for time approx. 500 ms
            yield();
          }
          strftime(timeStringBuff, sizeof(timeStringBuff), "%Y-%m-%d+%H%%3A%M%%3A%S\0", &timeinfo);
          Serial.print("Time = ");
          Serial.println(timeStringBuff);
          Serial.println("Sending data...");
          sendData(); 
        } else {
          Serial.println("WiFi connection failed");
        } 
     }
  }
  
  //Go to sleep now
  Serial.println("Going to sleep now");
  Serial.println("So long and thanks for all the fish");
  esp_deep_sleep_start();
  Serial.println("WARNING: This should never be printed");
}

void loop() {
  // This will never run so it can be empty
}

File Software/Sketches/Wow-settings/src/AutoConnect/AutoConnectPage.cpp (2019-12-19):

/**
 *  AutoConnect portal site web page implementation.
 *  @file   AutoConnectPage.h
 *  @author hieromon@gmail.com
 *  @version    1.1.0
 *  @date   2019-10-15
 *  @copyright  MIT license.
 */

#if defined(ARDUINO_ARCH_ESP8266)
#include <ESP8266WiFi.h>
extern "C" {
#include <user_interface.h>
}
#elif defined(ARDUINO_ARCH_ESP32)
#include <esp_spi_flash.h>
#include <WiFi.h>
#define ENC_TYPE_NONE WIFI_AUTH_OPEN
#endif
#include "AutoConnect.h"
#include "AutoConnectPage.h"
#include "AutoConnectCredential.h"

/**< Basic CSS common to all pages */
const char AutoConnect::_CSS_BASE[] PROGMEM = {
  "html{"
    "font-family:Helvetica,Arial,sans-serif;"
    "font-size:16px;"
    "-ms-text-size-adjust:100%;"
    "-webkit-text-size-adjust:100%;"
    "-moz-osx-font-smoothing:grayscale;"
    "-webkit-font-smoothing:antialiased"
  "}"
  "body{"
    "margin:0;"
    "padding:0"
  "}"
  ".base-panel{"
    "margin:0 22px 0 22px"
  "}"
  ".base-panel * label :not(.bins){"
    "display:inline-block;"
    "width:3.0em;"
    "text-align:right"
  "}"
  ".base-panel * .slist{"
    "width:auto;"
    "font-size:0.9em;"
    "margin-left:10px;"
    "text-align:left"
  "}"
  "input{"
    "-moz-appearance:none;"
    "-webkit-appearance:none;"
    "font-size:0.9em;"
    "margin:8px 0 auto"
  "}"
  ".lap{"
    "visibility:collapse"
  "}"
  ".lap:target{"
    "visibility:visible"
  "}"
  ".lap:target .overlap{"
    "opacity:0.7;"
    "transition:0.3s"
  "}"
  ".lap:target .modal_button{"
    "opacity:1;"
    "transition:0.3s"
  "}"
  ".overlap{"
    "top:0;"
    "left:0;"
    "width:100%;"
    "height:100%;"
    "position:fixed;"
    "opacity:0;"
    "background:#000;"
    "z-index:1000"
  "}"
  ".modal_button{"
    "border-radius:13px;"
    "background:#660033;"
    "color:#ffffcc;"
    "padding:20px 30px;"
    "text-align:center;"
    "text-decoration:none;"
    "letter-spacing:1px;"
    "font-weight:bold;"
    "display:inline-block;"
    "top:40%;"
    "left:40%;"
    "width:20%;"
    "position:fixed;"
    "opacity:0;"
    "z-index:1001"
  "}"
};

/**< non-marked list for UL */
const char AutoConnect::_CSS_UL[] PROGMEM = {
  ".noorder,.exp{"
    "padding:0;"
    "list-style:none;"
    "display:table"
  "}"
  ".noorder li,.exp{"
    "display:table-row-group"
  "}"
  ".noorder li label, .exp li *{"
    "display:table-cell;"
    "width:auto;"
    "text-align:right;"
    "padding:10px 0.5em"
  "}"
  ".noorder input[type=\"checkbox\"]{"
    "-moz-appearance:checkbox;"
    "-webkit-appearance:checkbox"
  "}"
  ".noorder input[type=\"radio\"]{"
    "margin-right:0.5em;"
    "-moz-appearance:radio;"
    "-webkit-appearance:radio"
  "}"
  ".noorder input[type=\"text\"]{"
    "width:auto"
  "}"
  ".noorder input[type=\"text\"]:invalid{"
    "background:#fce4d6"
  "}"
};

/**< Image icon for inline expansion, the lock mark. */
const char AutoConnect::_CSS_ICON_LOCK[] PROGMEM = {
  ".img-lock{"
    "display:inline-block;"
    "width:22px;"
    "height:22px;"
    "margin-top:14px;"
    "float:right;"
    "background: url(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) no-repeat"
  "}"
};

/**< INPUT button and submit style */
const char AutoConnect::_CSS_INPUT_BUTTON[] PROGMEM = {
  "input[type=\"button\"],input[type=\"submit\"],button[type=\"submit\"],button[type=\"button\"]{"
    "padding:8px 0.5em;"
    "font-weight:bold;"
    "letter-spacing:0.8px;"
    "color:#fff;"
    "border:1px solid;"
    "border-radius:2px;"
    "margin-top:12px"
  "}"
  "input[type=\"button\"],button[type=\"button\"]{"
    "background-color:#1b5e20;"
    "border-color:#1b5e20;"
    "width:15em"
  "}"
  ".aux-page input[type=\"button\"],button[type=\"button\"]{"
    "font-weight:normal;"
    "padding:8px 14px;"
    "margin:12px;"
    "width:auto"
  "}"
  "input#sb[type=\"submit\"]{"
    "width:15em"
  "}"
  "input[type=\"submit\"],button[type=\"submit\"]{"
    "padding:8px 30px;"
    "background-color:#006064;"
    "border-color:#006064"
  "}"
  "input[type=\"button\"],input[type=\"submit\"],button[type=\"submit\"]:focus,"
  "input[type=\"button\"],input[type=\"submit\"],button[type=\"submit\"]:active{"
    "outline:none;"
    "text-decoration:none"
  "}"
};

/**< INPUT text style */
const char AutoConnect::_CSS_INPUT_TEXT[] PROGMEM = {
  "input[type=\"text\"],input[type=\"password\"], .aux-page select{"
    "background-color:#fff;"
    "border:1px solid #ccc;"
    "border-radius:2px;"
    "color:#444;"
    "margin:8px 0 8px 0;"
    "padding:10px"
  "}"
  "input[type=\"text\"],input[type=\"password\"]{"
    "font-weight:300;"
    "width:auto;"
    "-webkit-transition:all 0.20s ease-in;"
    "-moz-transition:all 0.20s ease-in;"
    "-o-transition:all 0.20s ease-in;"
    "-ms-transition:all 0.20s ease-in;"
    "transition:all 0.20s ease-in"
  "}"
  "input[type=\"text\"]:focus,input[type=\"password\"]:focus{"
    "outline:none;"
    "border-color:#5C9DED;"
    "box-shadow:0 0 3px #4B8CDC"
  "}"
  "input.error,input.error:focus{"
    "border-color:#ED5564;"
    "color:#D9434E;"
    "box-shadow:0 0 3px #D9434E"
  "}"
  "input:disabled{"
    "opacity:0.6;"
    "background-color:#f7f7f7"
  "}"
  "input:disabled:hover{"
    "cursor:not-allowed"
  "}"
  "input.error::-webkit-input-placeholder,"
  "input.error::-moz-placeholder,"
  "input.error::-ms-input-placeholder{"
    "color:#D9434E"
  "}"
  ".aux-page label{"
    "display:inline;"
    "padding:10px 0.5em;"
  "}"
};
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

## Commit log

2019-11-15 Initial commit, empty KiCad project
    [liberation.kicad_pcb, liberation.sch]
2019-11-15 add kicad spesific .gitignore
2019-11-15 add scematic esp-wroom-32D and bme260
    [liberation.sch]
2019-11-16 making i2c conection and boot reset
    [liberation.sch]
2019-11-18 add liniar voltige regulator
    [liberation.sch]
2019-11-18 Add complete BOM
2019-11-18 schema en netlist af
    [liberation.sch]
2019-11-18 scheam af nu
    [liberation.sch]
2019-11-18 Update BOM and add bestelllijst
    [Bestellijst weerstation Bob Swinkels & Luca van Straaten.xlsx]
2019-11-18 pcs begin
    [liberation.kicad_pcb, liberation.sch]
2019-11-18 Make PCB design (almost) complete :p
    [liberation.kicad_pcb, liberation.sch]
2019-11-19 finich pcb and secmatic for ordering
    [liberation-B_Cu.gbr, liberation-B_Mask.gbr, liberation-B_Paste.gbr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]
2019-11-24 date titelblocks today
    [liberation.kicad_pcb, liberation.sch]
2019-11-24 date and titel block on pcb correct
    [liberation.kicad_pcb]
2019-11-24 Revert "date titelblocks today"
    This reverts commit 034fccc4a2562568847e0a5f0e35f07e7201a5d0.
    [liberation.kicad_pcb, liberation.sch]
2019-12-19 Add Arduino code

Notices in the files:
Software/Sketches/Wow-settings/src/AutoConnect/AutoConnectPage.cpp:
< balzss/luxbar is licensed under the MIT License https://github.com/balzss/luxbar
